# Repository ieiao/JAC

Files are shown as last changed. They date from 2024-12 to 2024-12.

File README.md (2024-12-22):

# Just A Clock

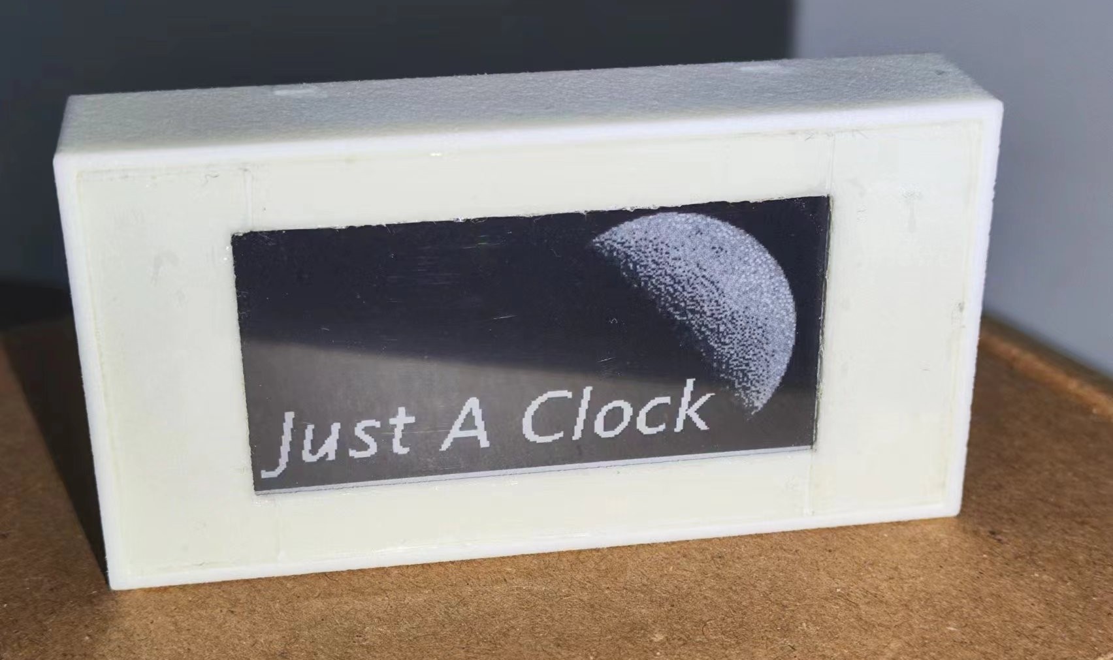
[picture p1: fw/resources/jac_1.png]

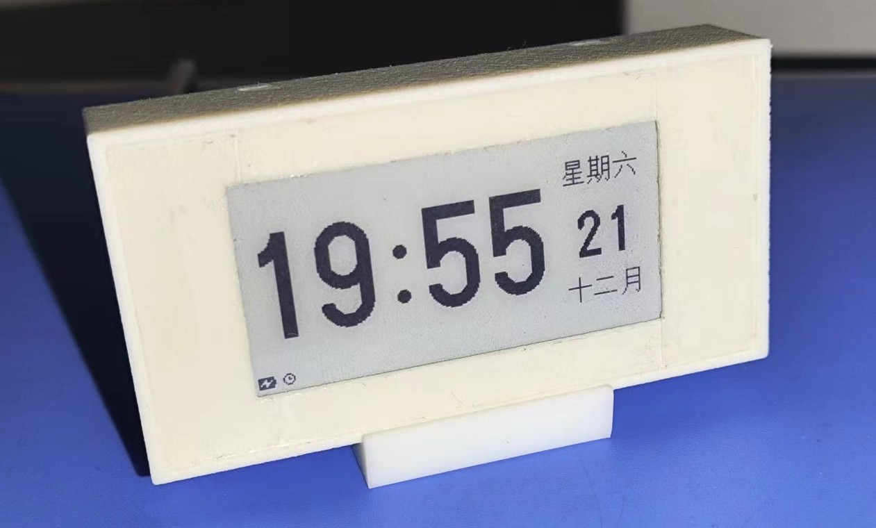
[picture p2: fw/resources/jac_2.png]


## How to compile

1. goto source directory

```
$ cd fw
```

2. compress web source file

```
$ cd spiffs_image
$ gzip -9 *
$ cd ..
```

3. build project

```
$ idf.py build
```

4. generate resources

```
$ # output is build/res/res.bin
$ ./tools/genres.sh
```

5. generate OTA file (optional)

```
$ # output is build/JAC_ota.bin
$ ./tools/genota.sh
```

6. flash

```
$ # resources and web archives must flash with app
$ python -m esptool --chip esp32c3 -b 460800 --before default_reset --after hard_reset write_flash --flash_mode dio --flash_size 4MB --flash_freq 80m 0x0 build/bootloader/bootloader.bin 0x8000 build/partition_table/partition-table.bin 0xd000 build/ota_data_initial.bin 0x90000 build/JAC.bin 0x380000 build/storage.bin 0x10000 build/res/res.bin
```

You can use the file generated in __step 5__ to update the firmware through OTA.

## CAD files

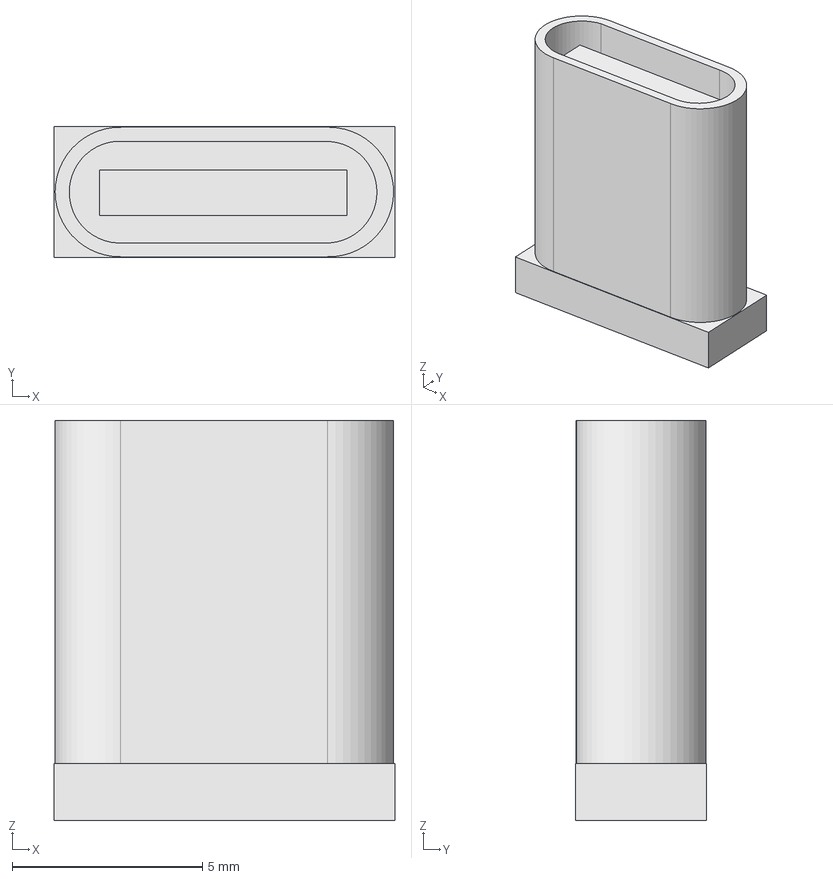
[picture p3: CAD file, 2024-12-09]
hw/3dmodels/C.step
8.94 x 3.45 x 10.5 mm

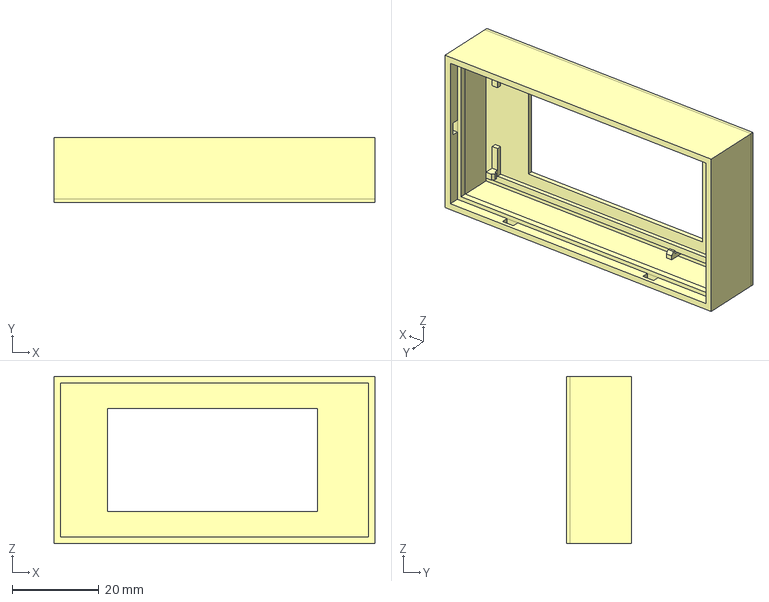
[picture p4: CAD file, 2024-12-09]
hw/case/JACCase.FCStd
74.1 x 14.9 x 38.6 mm

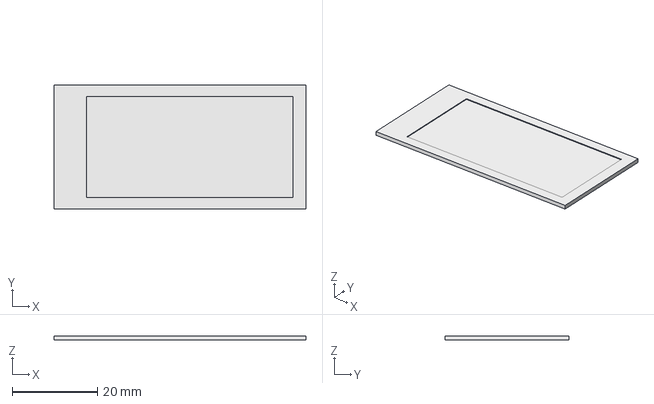
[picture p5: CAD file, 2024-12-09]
hw/3dmodels/213-Body.step
59.2 x 29.2 x 1.05 mm

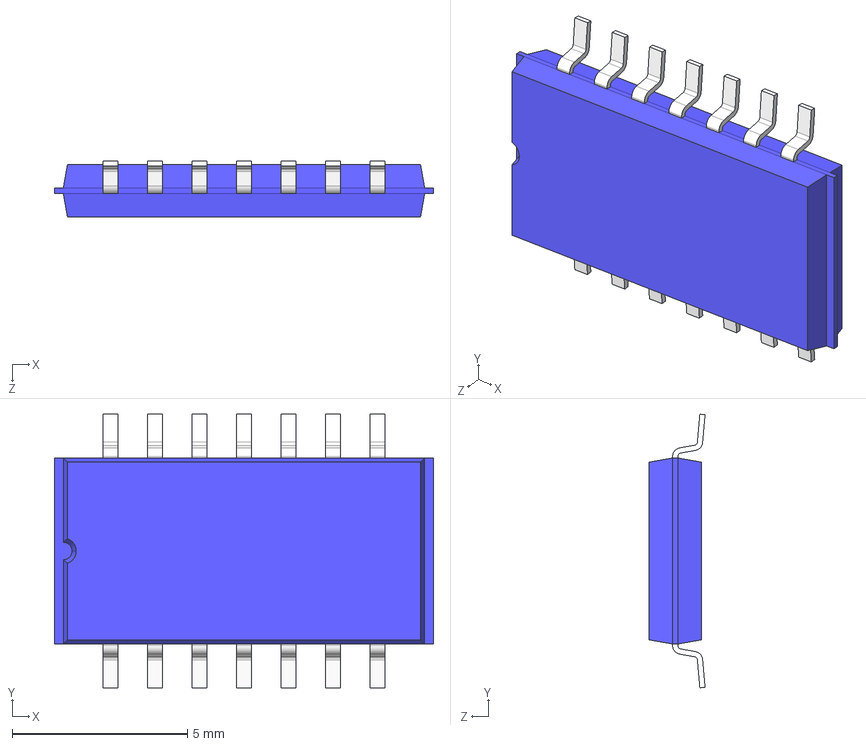
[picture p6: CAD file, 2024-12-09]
hw/3dmodels/SOP14.STEP
10.8 x 7.80 x 1.60 mm

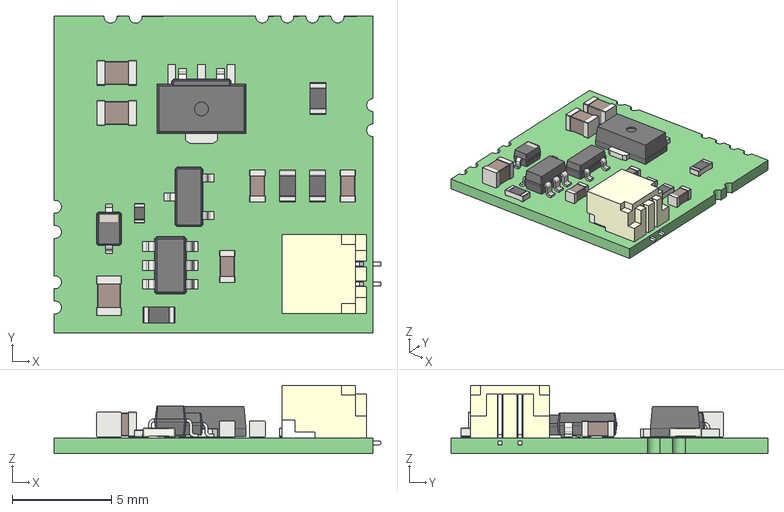
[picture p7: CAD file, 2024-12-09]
hw/3dmodels/4056M.step
16.5 x 16.0 x 3.45 mm
4056M PCB

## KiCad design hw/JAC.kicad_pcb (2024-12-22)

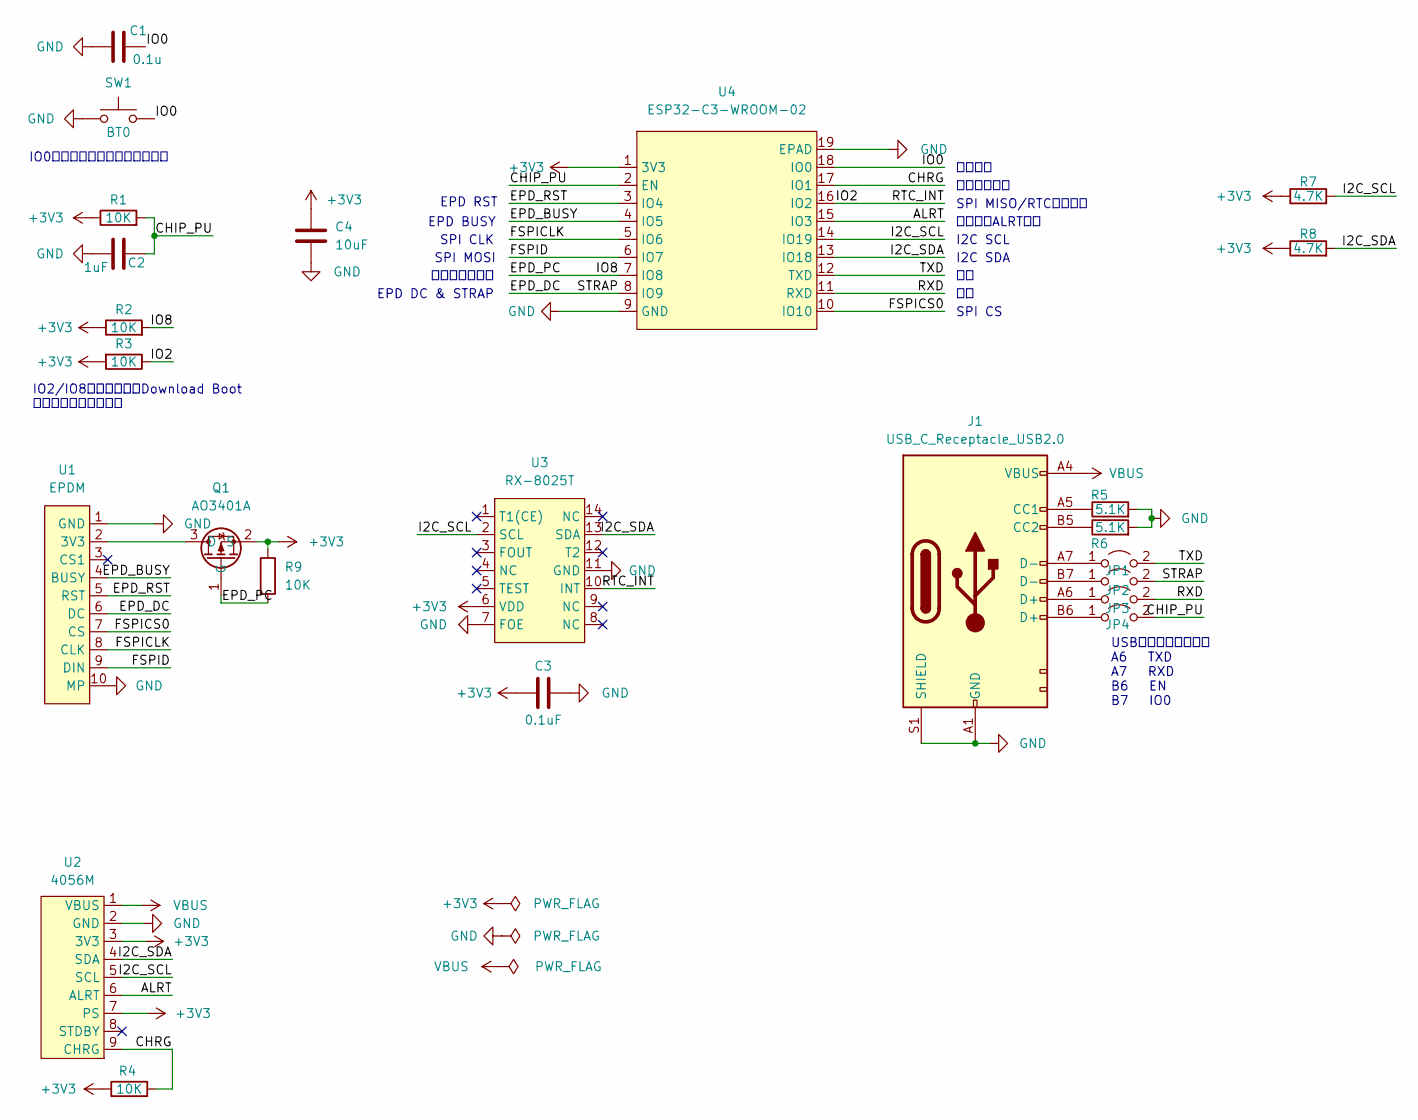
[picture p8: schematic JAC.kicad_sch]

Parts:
C1: 0.1u; C_0603_1608Metric
C2: 1uF; C_0603_1608Metric
C3: 0.1uF; C_0603_1608Metric
C4: 10uF; C_0805_2012Metric
J1: USB_C_Receptacle_USB2.0; TYPE-C-VERT
JP1, JP2, JP3, JP4: Jumper_2_Open; R_0402_1005Metric
Q1: AO3401A; SOT-23
R1, R2, R3, R4, R9: 10K; R_0603_1608Metric
R5, R6: 5.1K; R_0603_1608Metric
R7, R8: 4.7K; R_0603_1608Metric
SW1: BT0; SW_Push_SPST_NO_Alps_SKRK
U1: EPDM
U2: 4056M
U3: RX-8025T; SO-14_5.3x10.2mm_P1.27mm
U4: ESP32-C3-WROOM-02

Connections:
+3V3: C3.1, C4.1, Q1.2 (S), R1.1, R2.1, R3.2, R4.1, R7.1, R8.1, R9.1, U2.3 (3V3), U2.7 (PS), U3.6 (VDD), U4.1 (3V3)
/ALRT: U2.6 (ALRT), U4.15 (IO3)
/CHIP_PU: C2.2, JP4.2 (B), R1.2, U4.2 (EN)
/CHRG: R4.2, U2.9 (CHRG), U4.17 (IO1)
/EPD_BUSY: U1.4 (BUSY), U4.4 (IO5)
/EPD_DC: JP2.2 (B), U1.6 (DC), U4.8 (IO9)
/EPD_PC: Q1.1 (G), R2.2, R9.2, U4.7 (IO8)
/EPD_RST: U1.5 (RST), U4.3 (IO4)
/FSPICLK: U1.8 (CLK), U4.5 (IO6)
/FSPICS0: U1.7 (CS), U4.10 (IO10)
/FSPID: U1.9 (DIN), U4.6 (IO7)
/I2C_SCL: R7.2, U2.5 (SCL), U3.2 (SCL), U4.14 (IO19)
/I2C_SDA: R8.2, U2.4 (SDA), U3.13 (SDA), U4.13 (IO18)
/IO0: C1.2, SW1.2, U4.18 (IO0)
/IO2: R3.1, U3.10 (INT), U4.16 (IO2)
/RXD: JP3.2 (B), U4.11 (RXD)
/TXD: JP1.2 (B), U4.12 (TXD)
GND: C1.1, C2.1, C3.2, C4.2, J1.A1 (GND), J1.A12 (GND), J1.B1 (GND), J1.B12 (GND), J1.S1 (SHIELD), R5.2, R6.2, SW1.1, U1.1 (GND), U1.10 (MP), U2.2 (GND), U3.7 (FOE), U3.11 (GND), U4.9 (GND), U4.19 (EPAD)
unnamed: J1.A5 (CC1), R5.1
unnamed: J1.A6 (D+), JP3.1 (A)
unnamed: J1.A7 (D-), JP1.1 (A)
unnamed: J1.B5 (CC2), R6.1
unnamed: J1.B6 (D+), JP4.1 (A)
unnamed: J1.B7 (D-), JP2.1 (A)
unnamed: Q1.3 (D), U1.2 (3V3)
VBUS: J1.A4 (VBUS), J1.A9 (VBUS), J1.B4 (VBUS), J1.B9 (VBUS), U2.1 (VBUS)

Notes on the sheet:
墨水屏电源控制
IO2/IO8按照数据手册Download Boot 模式要求保持上拉状态
SPI CLK
SPI MISO/RTC中断输入
EPD BUSY
SPI CS
USB转串口侧引脚顺序 A6 TXD A7 RXD B6 EN B7 IO0
电源模块ALRT信号
EPD RST
EPD DC & STRAP
充电状态检测
IO0用作输入按键，用来唤醒系统
I2C SCL
SPI MOSI
I2C SDA
用户按键

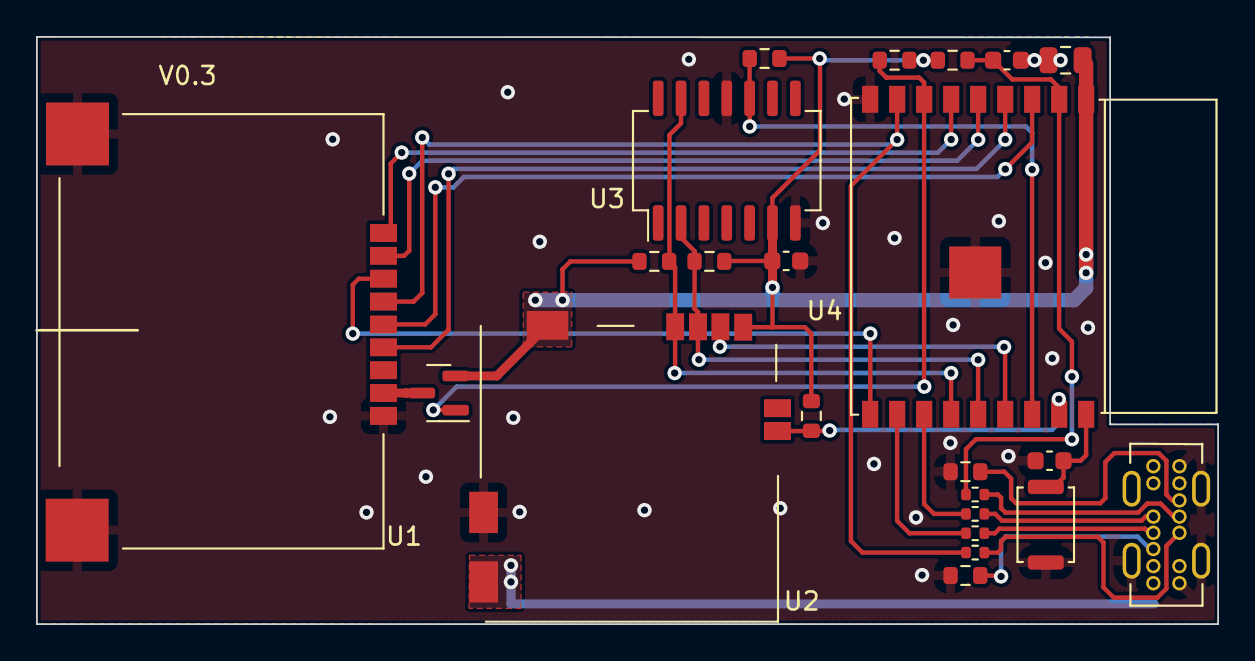
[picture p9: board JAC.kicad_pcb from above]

Board: 2 copper layers, 65.6 x 32.6 mm, 23 parts (0 on the bottom side), 26 nets.

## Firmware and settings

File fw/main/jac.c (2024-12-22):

#include <stdint.h>
#include <stdio.h>
#include <string.h>
#include <stdbool.h>
#include "display.h"
#include "esp_err.h"
#include "esp_system.h"
#include "freertos/FreeRTOS.h"
#include "freertos/portmacro.h"
#include "freertos/task.h"
#include "freertos/queue.h"
#include "esp_log.h"
#include "esp_sleep.h"
#include "esp_wifi.h"
#include "esp_netif.h"
#include "esp_mac.h"
#include "lwip/inet.h"
#include "nvs_flash.h"
#include "rx8025t.h"
#include "u8g2.h"
#include "jac.h"
#include "simple_theme.h"
#include "io.h"
#include "i2c.h"
#include "resources.h"
#include "http_server.h"
#include "esp_spiffs.h"
#include "cw2015.h"
#include "config.h"

static const char *TAG = "JAC";

RTC_DATA_ATTR struct jac_info info;
QueueHandle_t msg_queue;
TaskHandle_t msg_task;
TaskHandle_t config_task;
u8g2_t u8g2;
extern struct simple_theme theme_default;

uint8_t get_wakeup_cause(void)
{
    uint8_t cause = JAC_WAKEUP_NONE;
    uint64_t iomask;

    if (esp_reset_reason() == ESP_RST_DEEPSLEEP) {
        if (esp_sleep_get_wakeup_cause() == ESP_SLEEP_WAKEUP_GPIO) {
            iomask = esp_sleep_get_gpio_wakeup_status();
            if (iomask & BIT(BUTTON_GPIO))
                cause = JAC_WAKEUP_BUTTON;
            else if (iomask & BIT(CHRG_GPIO))
                cause = JAC_WAKEUP_CHARGE;
            else if (iomask & BIT(RTC_WAKE_GPIO))
                cause = JAC_WAKEUP_RTC;
            else if (iomask & BIT(CW_ALRT_GPIO))
                cause = JAC_WAKEUP_BATT_ALRT;
        }
    }

    return cause;
}

void checking_charging_state(void)
{
    int l = read_charging_state();

    if (l == 0)
        info.flags |= JAC_FLAG_CHARGING;
    else
        info.flags &= ~JAC_FLAG_CHARGING;
}

void jac_init()
{
    info.u8g2 = &u8g2;
    info.theme = &theme_default;

    pin_init();
    i2c_master_init();
    resources_init();
    rx8025t_init();
    cw2015_init();
    display_init(info.u8g2);
}

void jac_status_checking(void)
{
    checking_charging_state();
    info.wakeup_cause = get_wakeup_cause();

    /* Load config when first boot or after flash. */
    if (!(info.flags & JAC_FLAG_CONFIGURED) || info.wakeup_cause == JAC_WAKEUP_NONE)
        config_load(&info);
}

void jac_deep_sleep(void)
{
    display_wait_idle(WAIT_IDLE_MODE_DEFAULT);
    display_powersave(info.u8g2, 2);
    pin_deepsleep_setup(&info);
    ESP_LOGI(TAG, "Enter deep sleep");
    esp_deep_sleep_start();
}

static void wifi_event_handler(void *arg, esp_event_base_t event_base,
                               int32_t event_id, void *event_data)
{
    if (event_id == WIFI_EVENT_AP_STACONNECTED) {
        wifi_event_ap_staconnected_t *event = (wifi_event_ap_staconnected_t *)event_data;
        ESP_LOGI(TAG, "station " MACSTR " join, AID=%d",
                 MAC2STR(event->mac), event->aid);
    } else if (event_id == WIFI_EVENT_AP_STADISCONNECTED) {
        wifi_event_ap_stadisconnected_t *event = (wifi_event_ap_stadisconnected_t *)event_data;
        ESP_LOGI(TAG, "station " MACSTR " leave, AID=%d",
                 MAC2STR(event->mac), event->aid);
    }
}

static void jac_config_task(void *pvParameters)
{
    while(1) {
        uint32_t v = ulTaskNotifyTake(pdTRUE, 0);

        /* Set time&date */
        if (v & 0x01) {
            info.year_add_value = info.dt.year - (info.dt.year % 100);
            rx8025t_set_datetime(&info.dt);
            rx8025t_set_mark();
            rx8025t_enable_update_intr();
            if (is_cw2015_sleep()) {
                cw2015_wakeup();
                vTaskDelay(pdMS_TO_TICKS(200));
                cw2015_read_soc(&info.soc);
                cw2015_write_athd(5);
            }
            config_set(KEY_CONFIGURED, 1);
            info.flags |= JAC_FLAG_CONFIGURED;
        }

        /* Set power saving duration */
        if (v & 0x02) {
            config_set(KEY_PS_BEGIN, info.ps_begin);
            config_set(KEY_PS_END, info.ps_end);
        }

        /* First boot */
        if (v & 0x04) {
            vTaskDelay(pdMS_TO_TICKS(500));
            memset(&info, 0, sizeof(struct jac_info));
            rx8025t_reset();
            if (!is_cw2015_sleep())
                cw2015_deepsleep();
            config_erase();
            esp_restart();
        }

        /* Reset */
        if (v & 0x80) {
            vTaskDelay(pdMS_TO_TICKS(500));
            config_deinit();
            esp_restart();
        }

        vTaskDelay(pdMS_TO_TICKS(50));
    }
}

int jac_config_init()
{
    xTaskCreate(jac_config_task, "config",
                configMINIMAL_STACK_SIZE, NULL,
                configMAX_PRIORITIES - 1, &config_task);

    config_init();
    esp_netif_init();
    esp_event_loop_create_default();
    nvs_flash_init();
    esp_netif_create_default_wifi_ap();

    wifi_init_config_t cfg = WIFI_INIT_CONFIG_DEFAULT();
    wifi_config_t wifi_config;
    esp_wifi_init(&cfg);

    esp_event_handler_register(WIFI_EVENT, ESP_EVENT_ANY_ID, &wifi_event_handler, NULL);

    memset(&wifi_config, 0, sizeof(wifi_config_t));
    wifi_config.ap.max_connection = 1;
    wifi_config.ap.authmode = WIFI_AUTH_OPEN;
    esp_read_mac(info.mac, ESP_MAC_WIFI_SOFTAP);
    sprintf((char *)&wifi_config.ap.ssid, "JAC-%02X%02X", info.mac[4], info.mac[5]);

    esp_wifi_set_mode(WIFI_MODE_AP);
    esp_wifi_set_config(ESP_IF_WIFI_AP, &wifi_config);

    esp_wifi_start();

    esp_netif_ip_info_t ip_info;
    esp_netif_get_ip_info(esp_netif_get_handle_from_ifkey("WIFI_AP_DEF"), &ip_info);

    char ip_addr[16];
    inet_ntoa_r(ip_info.ip.addr, ip_addr, 16);
    ESP_LOGI(TAG, "Set up softAP with IP: %s", ip_addr);

    esp_vfs_spiffs_conf_t conf = {
        .base_path = "/spiffs",
        .partition_label = NULL,
        .max_files = 10,
        .format_if_mount_failed = true
    };

    esp_vfs_spiffs_register(&conf);
    http_server_start(msg_queue);

    return 0;
}

void jac_config_process(void)
{
    int count = 0;

    jac_config_init();

    dispart(info.theme->config_wait, &info);
    display_wait_idle(WAIT_IDLE_MODE_LOOP);
    display_powersave(info.u8g2, 2);
    epdm_poweroff();

    while(1)
    {
        vTaskDelay(10000/portTICK_PERIOD_MS);
        count++;
        if (count >= 12) {
            /* 2 mins, check any device are connected. */
            wifi_sta_list_t sta_list;
            esp_wifi_ap_get_sta_list(&sta_list);
            if (sta_list.num == 0) {
                ESP_LOGI(TAG, "Timeout, retting");
                esp_restart();
            }
        }
    }
}

bool jac_in_power_saving(void)
{
    bool ret = false;

    if (info.ps_begin == info.ps_end) {
        ret = false;
    } else if (info.ps_begin > info.ps_end) {
        if (info.dt.hours >= info.ps_begin ||
            info.dt.hours < info.ps_end)
            ret = true;
    } else if (info.ps_begin < info.ps_end) {
        if (info.dt.hours >= info.ps_begin &&
            info.dt.hours < info.ps_end)
            ret = true;
    }

    return ret;
}

void app_main(void)
{
    jac_init();
    jac_status_checking();

    /* Have to check fault state after jac_core_prepare called. */
    if (info.flags & JAC_FLAG_COREFAULT) {
        dispart(info.theme->core_failure, &info);
        jac_deep_sleep();
    }

    /* Checking first boot and power lost. */
    if (!(info.flags & JAC_FLAG_CONFIGURED) ||
        !is_rx8025t_configurated()) {
        if (info.wakeup_cause == JAC_WAKEUP_BUTTON) {
            /* execute config. */
            ESP_LOGI(TAG, "Starting config process");
            jac_config_process();
        } else {
            ESP_LOGI(TAG, "JAC not configurated, sleep now");
            dispart(info.theme->welcome, &info);
            rx8025t_reset();
            if (!is_cw2015_sleep()) {
                ESP_LOGI(TAG, "CW2015 not sleep, sleep now");
                cw2015_deepsleep();
            }
            jac_deep_sleep();
        }
    } else {
        if (info.wakeup_cause == JAC_WAKEUP_BATT_ALRT) {
            uint8_t alert;
            cw2015_read_alrt(&alert);
            info.flags |= JAC_FLAG_BATTDEAD;
            rx8025t_disable_intr();
            rx8025t_clear_flag();
            dispart(info.theme->battery_dead, &info);
            jac_deep_sleep();
        } else if (info.wakeup_cause == JAC_WAKEUP_BUTTON) {
            rx8025t_get_datetime(&info.dt);
            info.dt.year += info.year_add_value;
            if (jac_in_power_saving()) {
                dispart(info.theme->primary, &info);
                rx8025t_enable_update_intr();
                jac_deep_sleep();
            } else {
                /* execute config. */
                jac_config_process();
            }
        } else {
            uint8_t flag;

            if (info.flags & JAC_FLAG_BATTDEAD &&
                info.wakeup_cause == JAC_WAKEUP_CHARGE)
                info.flags &= ~JAC_FLAG_BATTDEAD;

            rx8025t_read_flag(&flag);
            rx8025t_clear_flag();
            rx8025t_disable_intr();

            rx8025t_get_datetime(&info.dt);
            info.dt.year += info.year_add_value;

            /* Read SOC immediately after flash, OTA and charger removed. */
            if (info.soc == 0 || info.wakeup_cause == JAC_WAKEUP_CHARGE)
                cw2015_read_soc(&info.soc);

            /* Read SOC every 30 minutes */
            if ((info.dt.minutes % 30) == 0) {
                uint8_t soc;
                cw2015_read_soc(&soc);
                /* Only allow new soc greater than old soc when it's charging. */
                if (soc > info.soc && info.flags & JAC_FLAG_CHARGING)
                    info.soc = soc;
            }

            if (jac_in_power_saving()) {
                rx8025t_disable_update_intr();
                rx8025t_set_alarm(info.ps_end, 0);
                rx8025t_enable_alarm_intr();
                dispart(info.theme->powersaving, &info);
            } else {
                rx8025t_disable_alarm_intr();
                rx8025t_enable_update_intr();
                dispart(info.theme->primary, &info);
            }

            jac_deep_sleep();
        }
    }
}

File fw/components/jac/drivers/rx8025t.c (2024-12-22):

#include <stdbool.h>

#include "rx8025t.h"
#include "i2c.h"
#include "bcd.h"

#define RX8025T_ADDR        0x32

#define SEC_REGISTER        0x00
#define RAM_REGISTER        0x07
#define MIN_ALARM_REG       0x08
#define EXT_REGISTER        0x0d
#define FLAG_REGISTER       0x0e
#define CTRL_REGISTER       0x0f

#define RUNNING_MARK        0xaa

static i2c_master_dev_handle_t dev_handle;

int rx8025t_stop(void)
{
    uint8_t v;
    int ret;

    ret = i2c_register_read_byte(dev_handle, CTRL_REGISTER, &v);
    if (ret)
        goto out;

    v |= 0x01;
    ret = i2c_register_write_byte(dev_handle, CTRL_REGISTER, v);
out:
    return ret;
}

int rx8025t_start(void)
{
    uint8_t v;
    int ret;

    ret = i2c_register_read_byte(dev_handle, CTRL_REGISTER, &v);
    if (ret)
        goto out;

    v &= ~0x01;
    ret = i2c_register_write_byte(dev_handle, CTRL_REGISTER, v);
out:
    return ret;
}

int rx8025t_set_datetime(struct date_time *dt)
{
    uint8_t datetime[7];

    datetime[0] = bin2bcd(dt->seconds);
    datetime[1] = bin2bcd(dt->minutes);
    datetime[2] = bin2bcd(dt->hours);
    datetime[4] = bin2bcd(dt->day);
    datetime[5] = bin2bcd(dt->month);
    datetime[6] = bin2bcd(dt->year % 100);

    if (dt->week == 7)
        datetime[3] = 0x01;
    else
        datetime[3] = 0x01 << dt->week;

    return i2c_register_write_bytes(dev_handle, SEC_REGISTER, datetime, sizeof(datetime));
}

int rx8025t_get_datetime(struct date_time *dt)
{
    uint8_t datetime[7];
    int ret;

    ret = i2c_register_read_bytes(dev_handle, SEC_REGISTER, datetime, sizeof(datetime));
    if (ret)
        return ret;

    dt->seconds = bcd2bin(datetime[0]);
    dt->minutes = bcd2bin(datetime[1]);
    dt->hours   = bcd2bin(datetime[2]);
    dt->day     = bcd2bin(datetime[4]);
    dt->month   = bcd2bin(datetime[5]);
    dt->year    = bcd2bin(datetime[6]);

    switch (datetime[3]) {
        case 0x01: dt->week = 7; break;
        case 0x02: dt->week = 1; break;
        case 0x04: dt->week = 2; break;
        case 0x08: dt->week = 3; break;
        case 0x10: dt->week = 4; break;
        case 0x20: dt->week = 5; break;
        case 0x40: dt->week = 6; break;
        default:
            break;
    }

    return 0;
}

int rx8025t_set_ram(uint8_t v)
{
    return i2c_register_write_byte(dev_handle, RAM_REGISTER, v);
}

int rx8025t_get_ram(uint8_t *v)
{
    return i2c_register_read_byte(dev_handle, RAM_REGISTER, v);
}

int rx8025t_disable_intr(void)
{
    uint8_t v;
    int ret;

    /* Disable UIE & TIE & AIE. */
    ret = i2c_register_read_byte(dev_handle, CTRL_REGISTER, &v);
    if (ret)
        goto out;

    v &= ~0x38;
    ret = i2c_register_write_byte(dev_handle, CTRL_REGISTER, v);
out:
    return ret;
}

int rx8025t_clear_flag(void)
{
    uint8_t v;
    int ret;

    ret = i2c_register_read_byte(dev_handle, FLAG_REGISTER, &v);
    if (ret)
        goto out;

    v &= ~0x3b;
    ret = i2c_register_write_byte(dev_handle, FLAG_REGISTER, v);
out:
    return ret;
}

int rx8025t_read_flag(uint8_t *flag)
{
    int ret;

    ret = i2c_register_read_byte(dev_handle, FLAG_REGISTER, flag);
    if (ret)
        goto out;

    *flag &= 0x38;
out:
    return ret;
}

int rx8025t_read_ext(uint8_t *ext)
{
    return i2c_register_read_byte(dev_handle, EXT_REGISTER, ext);
}

int rx8025t_clear_uie_flag(void)
{
    uint8_t v;
    int ret;

    ret = i2c_register_read_byte(dev_handle, FLAG_REGISTER, &v);
    if (ret)
        goto out;

    v &= ~0x20;
    ret = i2c_register_write_byte(dev_handle, FLAG_REGISTER, v);
out:
    return ret;
}

int rx8025t_enable_update_intr(void)
{
    uint8_t v;
    int ret;

    /* Clear UF first. */
    ret = rx8025t_clear_uie_flag();
    if (ret)
        goto out;

    /* Set minute update interrupt. */
    ret = i2c_register_read_byte(dev_handle, EXT_REGISTER, &v);
    if (ret)
        goto out;

    v |= 0x20;
    ret = i2c_register_write_byte(dev_handle, EXT_REGISTER, v);
    if (ret)
        goto out;

    /* Enable UIE. */
    ret = i2c_register_read_byte(dev_handle, CTRL_REGISTER, &v);
    if (ret)
        goto out;

    v |= 0x20;
    ret = i2c_register_write_byte(dev_handle, CTRL_REGISTER, v);
out:
    return ret;
}

int rx8025t_disable_update_intr(void)
{
    uint8_t v;
    int ret;

    /* Disable UIE. */
    ret = i2c_register_read_byte(dev_handle, CTRL_REGISTER, &v);
    if (ret)
        goto out;

    v &= ~0x20;
    ret = i2c_register_write_byte(dev_handle, CTRL_REGISTER, v);
out:
    return ret;
}

int rx8025t_clear_aie_flag(void)
{
    uint8_t v;
    int ret;

    ret = i2c_register_read_byte(dev_handle, FLAG_REGISTER, &v);
    if (ret)
        goto out;

    v &= ~0x08;
    ret = i2c_register_write_byte(dev_handle, FLAG_REGISTER, v);
out:
    return ret;
}

int rx8025t_enable_alarm_intr(void)
{
    uint8_t v;
    int ret;

    /* Clear AF first. */
    ret = rx8025t_clear_aie_flag();
    if (ret)
        goto out;

    /* Set Alarm. */
    ret = i2c_register_read_byte(dev_handle, EXT_REGISTER, &v);
    if (ret)
        goto out;

    v |= 0x40;
    ret = i2c_register_write_byte(dev_handle, EXT_REGISTER, v);
    if (ret)
        goto out;

    /* Enable AIE. */
    ret = i2c_register_read_byte(dev_handle, CTRL_REGISTER, &v);
    if (ret)
        goto out;

    v |= 0x08;
    ret = i2c_register_write_byte(dev_handle, CTRL_REGISTER, v);
out:
    return ret;
}

int rx8025t_disable_alarm_intr(void)
{
    uint8_t v;
    int ret;

    /* Disable AIE. */
    ret = i2c_register_read_byte(dev_handle, CTRL_REGISTER, &v);
    if (ret)
        goto out;

    v &= ~0x08;
    ret = i2c_register_write_byte(dev_handle, CTRL_REGISTER, v);
out:
    return ret;
}

int rx8025t_set_alarm(uint8_t hour, uint8_t minute)
{
    int ret;
    uint8_t d[3];

    d[0] = bin2bcd(minute);
    d[1] = bin2bcd(hour);
    d[2] = 0x80;

    ret = i2c_register_write_bytes(dev_handle, MIN_ALARM_REG, d, 3);
    return ret;
}

int rx8025t_init(void)
{
    return i2c_master_add_device(RX8025T_ADDR, &dev_handle);
}

int rx8025t_reset(void)
{
    uint8_t v;
    int ret;

    /* Disable timer. */
    ret = i2c_register_read_byte(dev_handle, EXT_REGISTER, &v);
    if (ret)
        goto out;

    v &= ~0x10;
    ret = i2c_register_write_byte(dev_handle, EXT_REGISTER, v);
    if (ret)
        goto out;

    ret = rx8025t_disable_intr();
    if (ret)
        goto out;

    ret = rx8025t_clear_flag();
    if (ret)
        goto out;

    ret = rx8025t_set_ram(0);
    if (ret)
        goto out;

    ret = rx8025t_stop();
out:
    return ret;
}

int rx8025t_set_mark(void)
{
    return rx8025t_set_ram(RUNNING_MARK);
}

bool is_rx8025t_configurated(void)
{
    int ret;
    uint8_t mark;

    ret = rx8025t_get_ram(&mark);
    if (ret)
        return false;

    if (mark != RUNNING_MARK)
        return false;

    return true;
}

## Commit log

2024-12-22 Prepareing JAC
    [JAC.kicad_pcb, JAC.kicad_sch, partitions.csv]
2024-12-22 Adjust battery icon coordinate
2024-12-22 fw: Add powersaving mode indicator
2024-12-22 fw: EPD reset pin also need hold during update
2025-01-05 fw: fix year add value
    [jac.c]
2025-02-23 fw: fix year add not read correctly
    [jac.c]
